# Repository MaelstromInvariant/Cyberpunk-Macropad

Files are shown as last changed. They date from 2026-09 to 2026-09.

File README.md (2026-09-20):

# Cyberpunk Macro-Pad

A cyberpunk-themed 6-key macropad with a rotary encoder, OLED display, and RGB lighting.
(Its awesome ik :3)


## Features

* 6 MX-style mechanical switches
* EC11E rotary encoder
* Encoder push button
* 0.91" OLED display
* 2× SK6812 RGB LEDs
* USB-C
* Seeed Studio XIAO RP2040
* Custom PCB
* Custom 3D-printed case

## BOM
| Component |Quantity |
| --- | ---  |
| Seeed Studio Xiao RP2040 | 1 |
| 0.91 inch OLED | 1|
| Diodes | 7|
| EC11E Rotary Encoder | 1  |
| SK6812 | 2 |
| MX Switches  | 6 |
| Keycaps | 6|
| M3x16mm Screws |2|
| M3x5x14mm heatset-inserts |2|
| Serplex 12-in-1 Soldering Iron Tool Kit 80W (or any other soldering iron) |1|
| Soldering wire|1|

## Controls

| Control | Function |
| --- | ---  |
| PrtSc | Screenshot |
| W,A,S,D | Movement keys |
| Alt+Tab | Switches tabs |
| Encoder clockwise | Volume up |
| Encoder counter-clockwise | Volume down |
| Encoder press | Play / Pause  |

## Why I made it

idk looks cool ig

## Hardware

The macropad is built around a Seeed Studio XIAO RP2040.

The six switches are arranged as a small keyboard matrix. The rotary encoder is connected separately, and the encoder's push button is used as a media control.

The PCB also has two SK6812 LEDs and an I2C connection for the OLED display.

## PCB

The PCB was designed in KiCad.

The PCB is relatively simple, but as an easter egg I added silkscreen labels to make it look like it was actually made by a Cyberpunk corporation.
I know the average user isn't even likely to see them, but I found it cool. ;)

The `PCB/` folder contains:

* KiCad schematic
* KiCad PCB layout
* KiCad project files

The `Production/` folder contains the manufacturing files, including the Gerbers.


## CAD

The case was designed in Fusion.

The `CAD/` folder contains the assembled STEP model.

The `Production/` folder contains the STL files for the upper and lower case.

The case consists of an upper and lower part, which are secured with two screws and two heat-set inserts.

I used grills above one of the LEDs so the user doesn't get blasted by unobstructed, pure and unfiltered 500 THz electromagnetic radiation 
(technically true).

The other LED is close to the keyboard and naturally creates an ambient underglow.
I decided to keep the area around the main keyboard slightly exposed to give it the Cyberpunk vibe.


## Firmware

The firmware is written using QMK.

The QMK keyboard files are located in:
`Firmware/keyboard/`

The keyboard uses a 6-key matrix and supports the rotary encoder, OLED display, RGB lighting, and media controls.
The OLED panel displays an eye-animation which reacts when you press a key!

👁️👄👁️ 

## What I learnt
- KiCad
- DRC
- PCB and schematics design
- Debugging PCB design issues
- How keyboard matrices work
- Fusion
- QMK
- GitHub
- Creating a prototype model to virtually put it all together

## Future Improvements
- Add better OLED animations
- Add configurable RGB effects
- Improve the LED diffusion
- Possibly add a buzzer or additional features

## AI Usage

I used AI to better understand some of the components and concepts involved and I heavily relied on Claude while writing the QMK firmware because I was new to QMK. I also used Claude, ChatGPT, and Copilot to review the project and help find bugs and inconsistencies.

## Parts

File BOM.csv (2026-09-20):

Component | Quantity | Approximate Cost(in rupees)
Unsoldered Seeed XIAO RP2040 | 1 | 500
EC11E Rotary Encoder | 1 | 500
Diodes | 7 | 15
SK6812 LEDs | 2 | 30
MX style switches | 6 | 300
Keycaps | 6 | 600
M3x16mm Screws | 2 | 5
M3x5x14 heatset-inserts | 2 | 50
Serplex 12-in-1 Soldering Iron Tool Kit 80W | 1 | 1600
0.8mm Greenartz Soldering wire rosin core 50g lead-free | 1 | 400

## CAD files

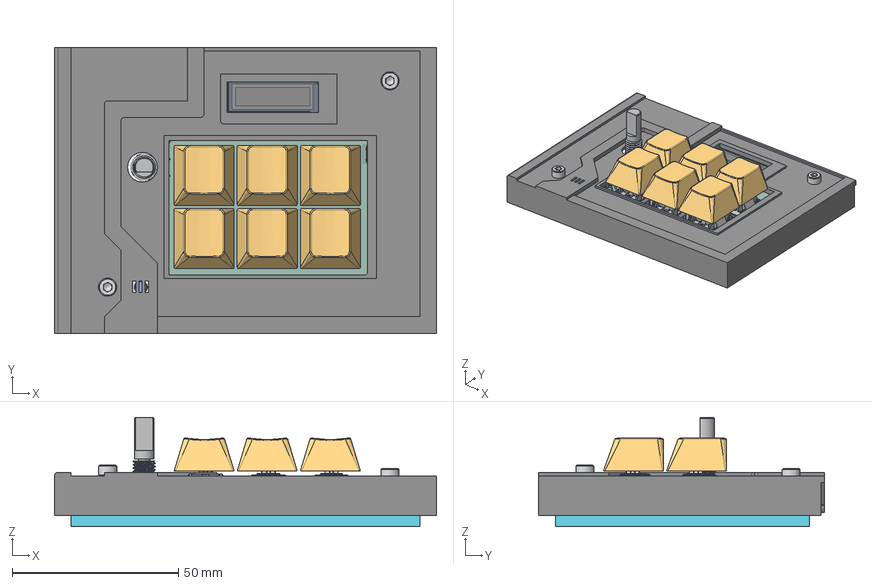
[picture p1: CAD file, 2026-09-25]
CAD/Cyberpunk Macro-Pad (Assembled).step
115.0 x 86.0 x 32.9 mm
0.91in oled Module - Board
0.91in OLED - Folded Flush - Without Glass
0603 Capacitor x 9
0603 Resistor x 5
SOT23-3
Diode (SOD-323)

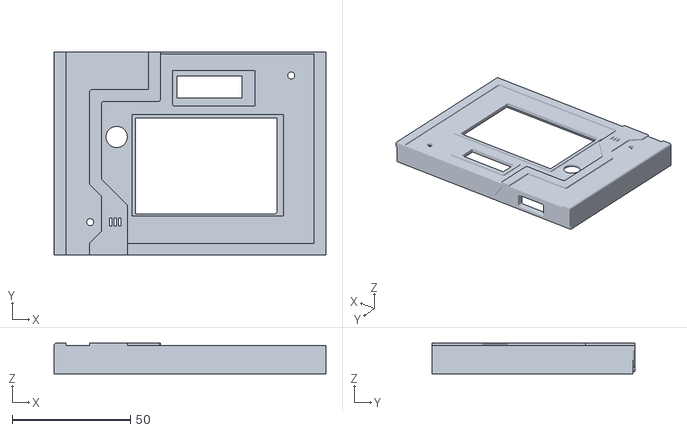
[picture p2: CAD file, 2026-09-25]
Production/UPPERCASE.stl
115.0 x 86.0 x 13.0

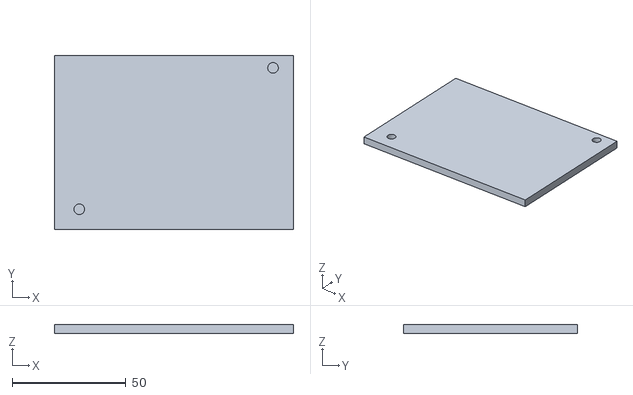
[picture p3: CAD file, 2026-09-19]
Production/LOWERCASE.stl
105.0 x 76.5 x 4.00

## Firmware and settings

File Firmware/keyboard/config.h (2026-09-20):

#pragma once

// OLED
#define I2C_DRIVER I2CD1
#define I2C1_SDA_PIN GP6
#define I2C1_SCL_PIN GP7

#define OLED_DISPLAY_ADDRESS 0x3C
#define OLED_DISPLAY_128X32
#define OLED_DISPLAY_WIDTH 128
#define OLED_DISPLAY_HEIGHT 32
#define OLED_BRIGHTNESS 180
#define OLED_UPDATE_INTERVAL 50
// RGB LEDs
#define WS2812_DI_PIN GP3
#define RGBLIGHT_LED_COUNT 2
#define RGBLIGHT_LIMIT_VAL 100
// Encoder
#define ENCODER_MAP_KEY_DELAY 10

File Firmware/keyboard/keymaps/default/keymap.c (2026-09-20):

#include QMK_KEYBOARD_H

#ifdef OLED_ENABLE
#include "oled_driver.h"
#endif

enum layer_names {
    _BASE,
};

// layout
const uint16_t PROGMEM keymaps[][MATRIX_ROWS][MATRIX_COLS] = {
    [_BASE] = LAYOUT(
        KC_PSCR, KC_W,    LALT(KC_TAB), KC_MPLY,
        KC_A,    KC_S,    KC_D
    )
};

// encoder
const uint16_t PROGMEM encoder_map[][NUM_ENCODERS][NUM_DIRECTIONS] = {
    [_BASE] = { ENCODER_CCW_CW(KC_VOLD, KC_VOLU) }
};

#ifdef OLED_ENABLE

// eye
static uint8_t ex = 64, ey = 16;
static uint8_t tx = 64, ty = 16;
static uint16_t react_t = 0;
static bool reacting = false;
static bool blink = false;
static uint16_t blink_t = 0;
static bool surprised = false;

static void draw_eye(void) {
    const uint8_t left = 20, right = 108, top = 8, bottom = 23;
    for (uint8_t i = left; i <= right; i++) {
        oled_write_pixel(i, top, true);
        oled_write_pixel(i, bottom, true);
    }
    for (uint8_t i = top; i <= bottom; i++) {
        oled_write_pixel(left, i, true);
        oled_write_pixel(right, i, true);
    }
    if (blink) {
        for (uint8_t i = left + 5; i < right - 4; i++) {
            oled_write_pixel(i, 16, true);
            oled_write_pixel(i, 17, true);
        }
        return;
    }
    uint8_t r = surprised ? 5 : 3;
    for (int8_t dx = -r; dx <= r; dx++) {
        for (int8_t dy = -r; dy <= r; dy++) {
            if ((dx * dx) + (dy * dy) > (r * r)) continue;
            int px = ex + dx, py = ey + dy;
            if (px >= 0 && px < 128 && py >= 0 && py < 32) oled_write_pixel(px, py, true);
        }
    }
    if (!surprised && ex > left && ey > top) oled_write_pixel(ex - 1, ey - 1, false);
}

static void move_eye(void) {
    if (ex < tx) ex++;
    if (ex > tx) ex--;
    if (ey < ty) ey++;
    if (ey > ty) ey--;
}

static void react(uint8_t nx, uint8_t ny) {
    tx = nx;
    ty = ny;
    react_t = timer_read();
    reacting = true;
}

static void tick_blink(void) {
    uint16_t elapsed = timer_elapsed(blink_t);
    if (elapsed > 5150) {
        blink = false;
        blink_t = timer_read();
    } else if (elapsed > 5000) {
        blink = true;
    }
}

bool oled_task_user(void) {
    oled_clear();
    if (reacting && timer_elapsed(react_t) > 500) {
        tx = 64;
        ty = 16;
        reacting = false;
        surprised = false;
    }
    move_eye();
    tick_blink();
    draw_eye();
    oled_set_cursor(0, 0);
    oled_write("CYBER", false);
    oled_set_cursor(6, 0);
    oled_write("EYE", false);
    oled_set_cursor(0, 3);
    oled_write("READY", false);
    return false;
}

#endif // OLED_ENABLE

bool process_record_user(uint16_t keycode, keyrecord_t *record) {
#ifdef OLED_ENABLE
    if (record->event.pressed) {
        switch (keycode) {
            case KC_PSCR:      react(48, 12); break;
            case KC_W:         react(58, 12); break;
            case LALT(KC_TAB): react(80, 12); break;
            case KC_A:         react(48, 20); break;
            case KC_S:         react(64, 20); break;
            case KC_D:         react(80, 20); break;
            case KC_MPLY:
                surprised = true;
                react(64, 16);
                break;
        }
    }
#endif
    return true;
}

#ifdef OLED_ENABLE
// encoder
bool encoder_update_user(uint8_t index, bool cw) {
    if (index != 0) return true;
    if (cw) {
        tap_code(KC_VOLU);
        react(82, 16);
    } else {
        tap_code(KC_VOLD);
        react(46, 16);
    }
    return false;
}
#endif

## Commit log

2026-09-19 Fix CAD Assembly
    [Cyberpunk Macro-Pad (Assembled).step, LOWERCASE.stl, UPPERCASE.stl]
2026-09-19 Add README for Cyberpunk Macro-Pad project
    Added detailed description of the Cyberpunk Macro-Pad project, including features, controls, hardware, PCB design, CAD files, firmware, and AI usage.
2026-09-19 Enhance README with PCB design details
    Added descriptions about PCB design and features, including easter eggs and safety measures.
2026-09-19 Refine PCB description and AI usage section
    Updated README.md for clarity and grammar improvements.
2026-09-19 Enhance README with BOM and project insights
    Added BOM, learning points, and future improvements sections to README.
2026-09-19 Revise README for component specifications and assembly
    Updated component names and added details about screws and heatset inserts.
2026-09-19 Fix typos in README.md
    Corrected the spelling of 'KiCAD' to 'KiCad' and fixed the typo in 'M3x5mx14mm' to 'M3x5x14mm'.
2026-09-19 Fix formatting in BOM section of README
2026-09-20 Add BOM.csv with component details and costs
    [BOM.csv]
2026-09-20 Add M3 screws and heatset inserts to BOM
    [BOM.csv]
2026-09-20 Add soldering iron tool kit to README
2026-09-20 Change SK6812 LEDs cost to 100 rupees
    Updated the approximate cost of SK6812 LEDs from 30 to 100 rupees.
    [BOM.csv]
2026-09-20 Update price of Soldering Iron Tool Kit to 1600
    [BOM.csv]
2026-09-20 Modify costs for components in BOM.csv
    Updated the approximate costs for Diodes and SK6812 LEDs.
    [BOM.csv]
2026-09-20 Add soldering wire entry to BOM.csv
    [BOM.csv]
2026-09-20 Fix formatting of soldering wire entry in BOM.csv
    [BOM.csv]
2026-09-20 Add soldering wire requirement to README
2026-09-20 Clean up config.h by removing comments
    Removed commented sections for OLED, RGB LEDs, and Encoder.
2026-09-20 Clarify encoder_update_user function with comment
    Add comment to clarify encoder_update_user function.
2026-09-25 Polished 3D Model
    [Cyberpunk Macro-Pad (Assembled).step, UPPERCASE.stl]
2026-10-01 CAD updates
    [Cyberpunk Macro-Pad-NPTH.drl, Cyberpunk Macro-Pad-PTH.drl]
2026-10-31 Add soldering to skills learned section
2026-11-01 Update README with PCB design details and images
    Added images and details about the PCB design and features.
2026-11-01 Change PCB image dimensions in README.md
    Updated PCB image size in README.
2026-11-01 Change PCB image width to 600 pixels
    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
2026-11-01 Change PCB image height from 200 to 400
    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
2026-11-01 Update README with soldering skills note
    Added a note about soldering skills in the PCB section.
2026-11-04 Update BOM.csv to include product links
    Added product links for components in BOM.
2026-11-04 Update BOM.csv with new component entries
2026-11-04 Refactor BOM.csv for better readability and sources
    Updated BOM.csv to improve formatting and links.
2026-11-04 Add source link for SK6812 LEDs
    Updated SK6812 LEDs entry with a source link.
2026-11-04 Update M3 x 16mm Screws entry in BOM.csv
    Updated the price and added a URL for M3 x 16mm Screws.
2026-11-04 Modify BOM.csv with updated parts and links
    Updated quantities and added missing URLs for several components.
2026-11-04 Change keycap URL in BOM.csv
    Updated the URL for the MX-compatible keycaps.
2026-11-04 Change MX-style switches price to 180
    Updated the price of MX-style switches from 200 to 180.
2026-11-04 Remove duplicates and update soldering tool links
    Removed duplicate entries for soldering tools and updated product links.
2026-11-04 Fix and update soldering tool entries in BOM.csv
    Updated entries for soldering tools and solder wire, correcting formatting and adding new items.
2026-11-04 Update BOM.csv with final cost information
    Added final cost summary to BOM.
2026-11-04 Remove duplicate solder wire entry from BOM
    Removed duplicate entry for Greenartz 0.8mm Lead-free Rosin Core Solder Wire 25g in BOM.
2026-11-04 Revise BOM.csv with cost summary and item updates
    Updated BOM with cost summary and corrected item details.
2026-11-04 Remove cost summary from BOM.csv
    Removed cost summary section and related notes from BOM.csv.
2026-11-04 Revise cost estimates in README
    Updated cost details for PCB fabrication and 3D printing.
2026-11-04 Update README with BOM file reference
    Added a note to check the BOM file for more information.
